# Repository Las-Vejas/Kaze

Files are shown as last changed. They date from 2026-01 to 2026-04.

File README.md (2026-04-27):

<h1 align="center">
  <br>
  <a href="https://vejas.zip">
    kaze_logo_kanji_center
  </a>
  <br>
  <sub>Kaze</sub>
  <br>
</h1>

<div align="center">
  
  
  
  
</div>

<h4 align="center">An all-in-one ambient sensor for <a href="https://www.home-assistant.io/">Home Assistant</a>, powered by the ESP32-C6.</h4>

<br>

## Overview

Kaze is a compact ambient sensor that measures a wide range of environmental data and exposes it to Home Assistant via ESPHome. It supports **Zigbee, Wi-Fi, Bluetooth, and Thread** out of the box thanks to the ESP32-C6 module.

## Sensors

| Sensor | Measurements |
|---|---|
| BME680 | Temperature, Humidity, Pressure, CO₂ / AQI |
| TSL25911FN | Illuminance (lux), IR |
| WS2812B | RGB status LED |

## Connectivity

The ESP32-C6-MINI-1 module provides:
- Wi-Fi
- Bluetooth 5
- Thread / Matter
- Zigbee

These will be utilised to connect to your Home Assistant setup and provide temperature readings.

## Software

Firmware is written for **ESPHome**, making it seamless to integrate with Home Assistant. *(Work in progress)*

## Images

<p align="center">
  
  
  
  
</p>
<p align="center">
  
</p>

## Bill of Materials

### JLCPCB

| Item | Cost |
|---|---|
| PCB (5×) | $2.10 |
| Stencil | $7.00 |
| Shipping (Global Standard Direct Line) | $26.55 |

### LCSC Components

| Part | Mfr. | Qty | Unit Price | Ext. Price | LCSC# |
|---|---|-----|---|---|---|
| ESP32-C6-MINI-1-N4 | Espressif | 2 | $4.04 | $8.09 | [C5736265](https://www.lcsc.com/product-detail/C5736265.html) |
| BME680 | Bosch | 1 | $9.85 | $9.85 | [C125972](https://www.lcsc.com/product-detail/C125972.html) |
| TSL25911FN | AMS | 3 | $1.81 | $5.42 | [C176812](https://www.lcsc.com/product-detail/C176812.html) |
| MCP73831T-2ACI/OT | Microchip | 2 | $0.73 | $1.46 | [C424093](https://www.lcsc.com/product-detail/C424093.html) |
| AP2112K-3.3TRG1 (LDO 3.3V) | Tech Public | 5 | $0.09 | $0.47 | [C23380830](https://www.lcsc.com/product-detail/C23380830.html) |
| WS2812B-2020 (RGB LED) | Worldsemi | 10 | $0.08 | $0.83 | [C965555](https://www.lcsc.com/product-detail/C965555.html) |
| USB-C Receptacle 16P | Shou Han | 20 | $0.06 | $1.20 | [C2765186](https://www.lcsc.com/product-detail/C2765186.html) |
| Tactile Switch SPST | Alps Alpine | 5 | $0.13 | $0.65 | [C115357](https://www.lcsc.com/product-detail/C115357.html) |
| Cap 100nF 0402 | Samsung EM | 100 | $0.005 | $0.49 | [C16193311](https://www.lcsc.com/product-detail/C16193311.html) |
| Cap 4.7µF 0402 | Samsung EM | 20 | $0.009 | $0.18 | [C318563](https://www.lcsc.com/product-detail/C318563.html) |
| Cap 10µF 0402 | Samsung EM | 50 | $0.012 | $0.59 | [C3902158](https://www.lcsc.com/product-detail/C3902158.html) |
| Cap 1µF 16V 0402 | Samsung EM | 100 | $0.002 | $0.23 | [C29266](https://www.lcsc.com/product-detail/C29266.html) |
| Cap 1µF 10V 0402 | Samsung EM | 100 | $0.002 | $0.18 | [C14445](https://www.lcsc.com/product-detail/C14445.html) |
| Res 10kΩ 0402 | Yageo | 100 | $0.001 | $0.07 | [C60489](https://www.lcsc.com/product-detail/C60489.html) |
| Res 4.7kΩ 0402 | Yageo | 100 | $0.001 | $0.07 | [C105870](https://www.lcsc.com/product-detail/C105870.html) |
| Res 2.4kΩ 0402 | Yageo | 100 | $0.001 | $0.07 | [C137889](https://www.lcsc.com/product-detail/C137889.html) |
| Res 5.1kΩ 0402 | Yageo | 100 | $0.001 | $0.08 | [C105872](https://www.lcsc.com/product-detail/C105872.html) |
| Res 22Ω 0402 | Yageo | 100 | $0.001 | $0.07 | [C114765](https://www.lcsc.com/product-detail/C114765.html) |

### Other

| Item | Cost |
|---|---|
| LiPo Battery 3.7V 800mAh (802540) | $6.52 |
| LCSC Shipping | $9.50 |

### 💰 Total Cost Estimate

| | |
|---|---|
| LCSC components + shipping | ~$38.00 |
| JLCPCB PCB + stencil + shipping | ~$35.65 |
| Battery | $6.52 |
| Discounts | −$5.10 |
| **Total** | **~$76.67** |

> Shipping cost for JLCPCB can be roughly halved if ordered alongside another project.

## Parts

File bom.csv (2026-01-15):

Kaze BOM
JLCPCB BOM
Index | Item | Price | Note
1 | PCB from JLCPCB | 2.10 $US
2 | Stencil | 7.00 $US
3 | JLCPCB Shipping | 26.55 $US | Cheapest possible. (Global Standard Direct Line), possible to reduce in half if ordered with other project
Digikey BOM
Index | Manufacturer Part Number | Total Price | Description | Quantity | Pack Type | Digi-Key Part Number | Unit Price | Manufacturer Name | Reference Designator
1 | ESP32-C6-MINI-1-N4 | 9.02 $US | RF TXRX MOD BT WIFI PCB TH SMD | 2 | Cut Tape (CT) | 1965-ESP32-C6-MINI-1-H4CT-ND | 4.51 | Espressif Systems | U4
2 | SKRKAEE020 | 1.64 $US | SWITCH TACTILE SPST-NO 0.05A 12V | 4 | Cut Tape (CT) | 4809-SKRKAEE020CT-ND | 0.41000 | Alps Alpine | SW1, SW2
3 | BME680 | 17.30 $US | SENSOR GAS/HUM/PRES/TEMP I2C SPI | 2 | Cut Tape (CT) | 828-1077-1-ND | 8.65000 | Bosch Sensortec | U2
4 | TSL25911FN | 3.34 $US | SENSOR OPT AMBIENT 6 WFDFN | 2 | Cut Tape (CT) | TSL25911FNCT-ND | 1.67000 | ams-OSRAM USA INC. | U1
5 | 4684 | 3.95 $US | ADDRESS LED DISCRETE RGB | 1 | Bag | 1528-4684-ND | 3.95000 | Adafruit Industries LLC | D1, D2, D3, D4, D5
6 | USB4105-GF-A | 1.56 $US | CONN RCP USB2.0 TYP C 16P SMD RA | 2 | Cut Tape (CT) | 2073-USB4105-GF-ACT-ND | 0.78000 | GCT | P1
7 | AP2112K-3.3TRG1 | 0.44 $US | IC REG LINEAR 3.3V 600MA SOT-25 | 2 | Cut Tape (CT) | AP2112K-3.3TRG1DICT-ND | 0.22000 | Diodes Incorporated | U3
8 | MCP73831T-2ACI/OT | 1.52 $US | IC BATT CNTL LI-ION 1CEL SOT23-5 | 2 | Cut Tape (CT) | MCP73831T-2ACI/OTCT-ND | 0.76000 | Microchip Technology | U5
9 | CL05B104KP5VPNC | 0.74 $US | CAP CER 100NF 10V X7R 0402 | 20 | Cut Tape (CT) | 1276-CL05B104KP5VPNCCT-ND | 0.03700 | Samsung Electro-Mechanics | C1, C8, C10, C12, C13, C14, C15, C16, C2, C5
10 | CL05A475MO5NUNC | 0.32 $US | CAP CER 4.7UF 16V X5R 0402 | 4 | Cut Tape (CT) | 1276-6836-1-ND | 0.08000 | Samsung Electro-Mechanics | C11, C17
11 | CL05A106MP6NUN8 | 0.48 $US | CAP CER 10UF 10V X5R 0402 | 4 | Cut Tape (CT) | 1276-CL05A106MP6NUN8CT-ND | 0.12000 | Samsung Electro-Mechanics
12 | RC0402JR-0710KL | 0.12 $US | RES 10K OHM 5% 1/16W 0402 | 20 | Cut Tape (CT) | 311-10KJRCT-ND | 0.00600 | YAGEO
13 | RC0402JR-074K7L | 0.03 $US | RES 4.7K OHM 5% 1/16W 0402 | 10 | Cut Tape (CT) | 311-4.7KJRCT-ND | 0.00300 | YAGEO
14 | RC0402FR-0722RL | 0.07 $US | RES 22 OHM 1% 1/16W 0402 | 10 | Cut Tape (CT) | 311-22.0LRCT-ND | 0.00700 | YAGEO
15 | RC0402JR-072K4L | 0.20 $US | RES 2.4K OHM 5% 1/16W 0402 | 2 | Cut Tape (CT) | 311-2.4KJRCT-ND | 0.10000 | YAGEO
16 | RC0402FR-075K1L | 0.08 $US | RES 5.1K OHM 1% 1/16W 0402 | 10 | Cut Tape (CT) | 311-5.10KLRCT-ND | 0.00800 | YAGEO
17 | CL05A105KO5NNNC | 0.06 $US | CAP CER 1UF 16V X5R 0402 | 10 | Cut Tape (CT) | 1276-1067-1-ND | 0.00600 | Samsung Electro-Mechanics
18 | CL05A226MQ5N6J8 | 0.26 $US | CAP CER 22UF 6.3V X5R 0402 | 2 | Cut Tape (CT) | 1276-7090-1-ND | 0.13000 | Samsung Electro-Mechanics
TOTAL |  | 41.13 $US
TOTAL IN BOM |  | 76.78 $US

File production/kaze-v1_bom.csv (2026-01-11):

Designator | Footprint | Quantity | Value | LCSC Part #
C1, C4 | 0402 | 2 | 4.7u
C10, C11, C12, C14, C16, C2, C3, C8, C9 | 0402 | 9 | 100nf
C13, C15, C17, C18 | 0402 | 4 | 1uF
C19 | 0402 | 1 | 22uf
C5 | 0402 | 1 | 10uf
C6 | 0402 | 1 | 10u
C7 | 0402 | 1 | 100n
D1, D2, D3, D4, D5 | LED_WS2812B-2020_PLCC4_2.0x2.0mm | 5 | WS2812B-2020
IO2, IO3 | TestPoint_Pad_D3.0mm | 2 | TestPoint
J1 | PinHeader_2x01_P1.00mm_Vertical | 1 | Conn_01x02_Pin
P1 | USB_C_Receptacle_GCT_USB4105-xx-A_16P_TopMnt_Horizontal | 1 | USB_C_Plug_USB2.0
R1, R2 | 0402 | 2 | 5.1k
R10, R12, R8, R9_2, R9 | 0402 | 5 | 10k
R11 | 0402 | 1 | 4.7
R3, R4 | 0402 | 2 | 4.7k
R5, R6 | 0402 | 2 | 22
R7 | 0402 | 1 | 2.4k
SW1, SW2 | SW_Push_SPST_NO_Alps_SKRK | 2 | SW_Push
U1 | SOT-23-5 | 1 | MCP73831-2-OT
U2 | Bosch_LGA-8_3x3mm_P0.8mm_ClockwisePinNumbering | 1 | BME680
U3 | SOT-23-5 | 1 | AP2112K-3.3
U4 | ESP32-C6-MINI-1 | 1 | ESP32-C6-MINI-1
U5 | AMS_TSL25911FN | 1 | TSL25911FN
U6 | XCDR_SGP40-D-R4 | 1 | SGP40-D-R4

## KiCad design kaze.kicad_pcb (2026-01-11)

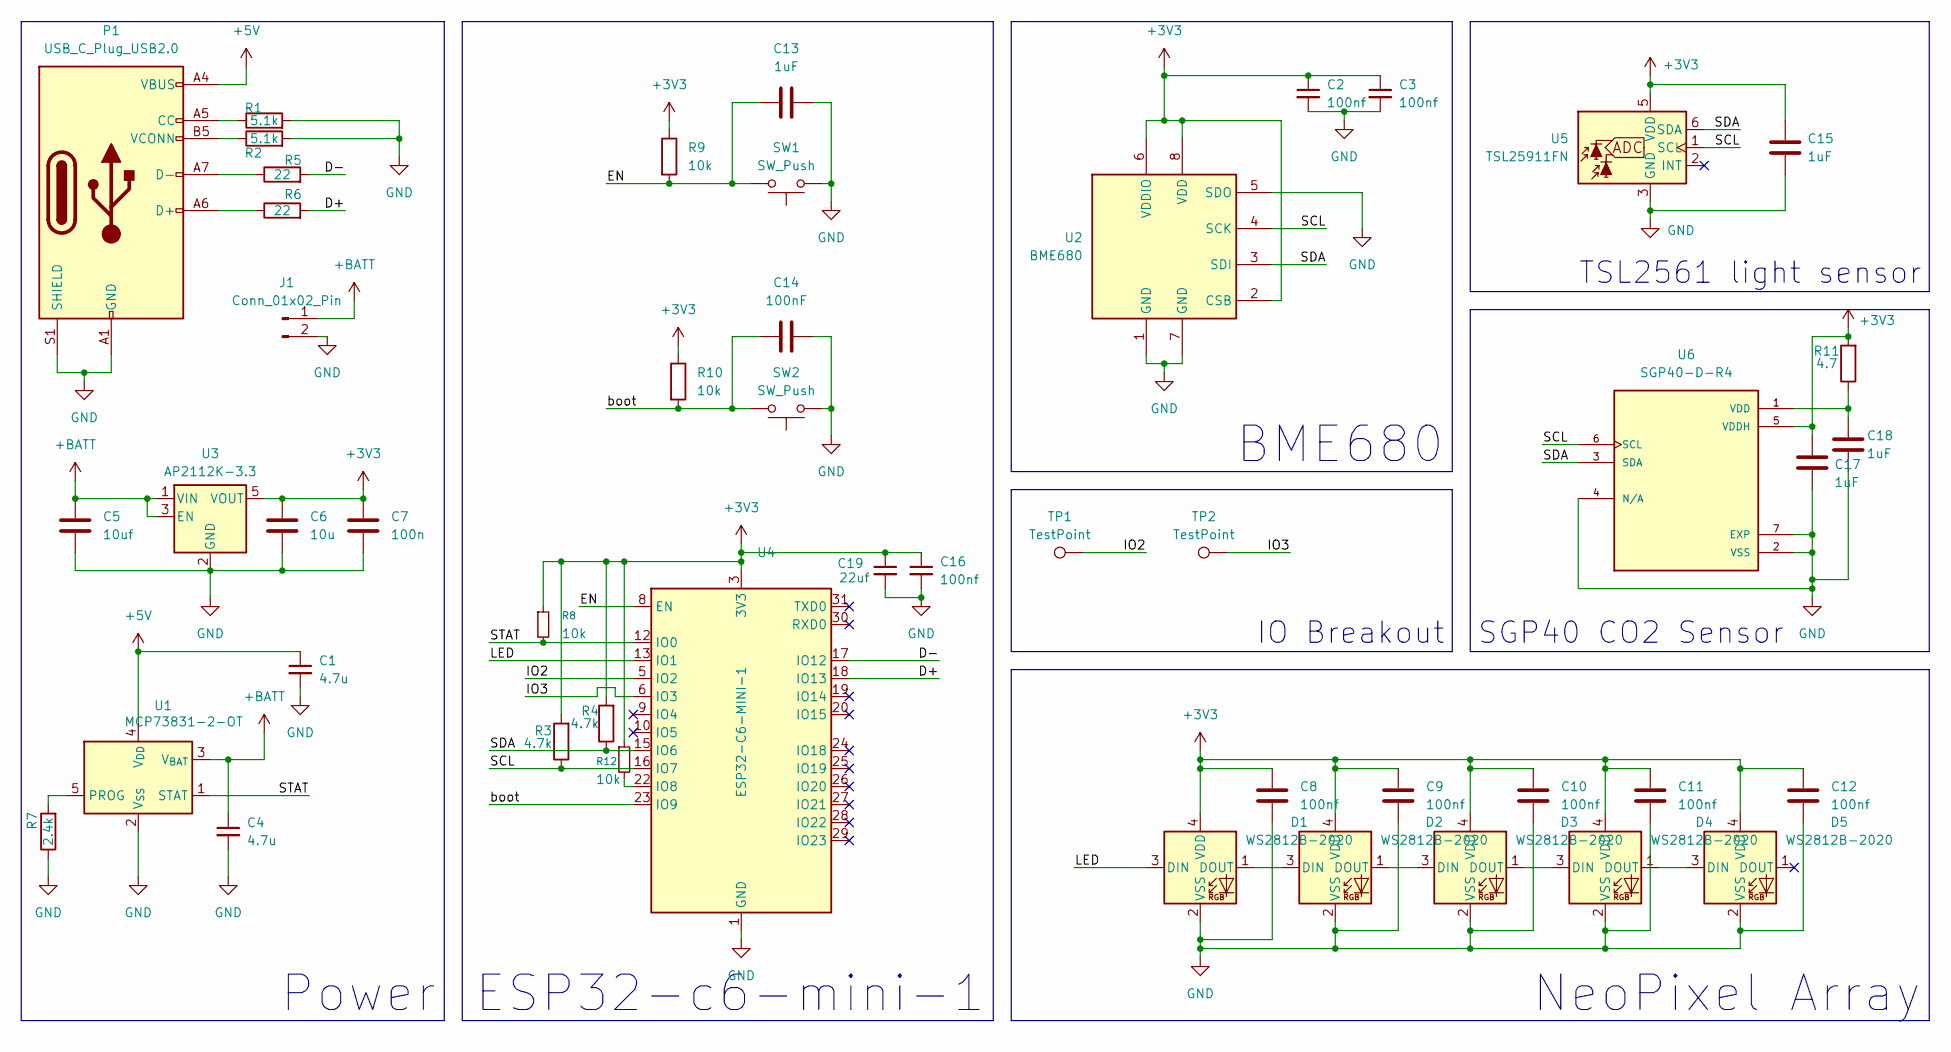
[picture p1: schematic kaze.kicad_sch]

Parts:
C1, C4: 4.7u; C_0402_1005Metric
C2, C3, C8, C9, C10, C11, C12, C16: 100nf; C_0402_1005Metric
C5: 10uf; C_0402_1005Metric
C6: 10u; C_0402_1005Metric
C7: 100n; C_0402_1005Metric
C13, C15, C17, C18: 1uF; C_0402_1005Metric
C14: 100nF; C_0402_1005Metric
C19: 22uf; C_0402_1005Metric
D1, D2, D3, D4, D5: WS2812B-2020; LED_WS2812B-2020_PLCC4_2.0x2.0mm
J1: Conn_01x02_Pin; PinHeader_2x01_P1.00mm_Vertical
P1: USB_C_Plug_USB2.0; USB_C_Receptacle_GCT_USB4105-xx-A_16P_TopMnt_Horizontal
R1, R2: 5.1k; R_0402_1005Metric
R3, R4: 4.7k; R_0402_1005Metric
R5, R6: 22; R_0402_1005Metric
R7: 2.4k; R_0402_1005Metric
R8, R9, R10, R12: 10k; R_0402_1005Metric
R11: 4.7; R_0402_1005Metric
SW1, SW2: SW_Push; SW_Push_SPST_NO_Alps_SKRK
TP1, TP2: TestPoint; TestPoint_Pad_D3.0mm
U1: MCP73831-2-OT; SOT-23-5
U2: BME680; Bosch_LGA-8_3x3mm_P0.8mm_ClockwisePinNumbering
U3: AP2112K-3.3; SOT-23-5
U4: ESP32-C6-MINI-1
U5: TSL25911FN; AMS_TSL25911FN
U6: SGP40-D-R4; XCDR_SGP40-D-R4; PARTREV 1.2

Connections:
+3V3: C2.1, C3.1, C6.1, C7.1, C8.1, C9.1, C10.1, C11.1, C12.1, C15.1, C16.1, C17.1, C19.1, D1.4 (VDD), D2.4 (VDD), D3.4 (VDD), D4.4 (VDD), D5.4 (VDD), R3.2, R4.2, R8.1, R9.1, R10.1, R11.2, R12.1, U2.2 (CSB), U2.6 (VDDIO), U2.8 (VDD), U3.5 (VOUT), U4.3 (3V3), U5.5 (VDD), U6.5 (VDDH); also elsewhere on the board
+5V: C1.1, P1.A4 (VBUS), P1.A9 (VBUS), P1.B4 (VBUS), P1.B9 (VBUS), U1.4 (V_{DD})
+BATT: C4.1, C5.1, J1.1, U1.3 (V_{BAT}), U3.1 (VIN), U3.3 (EN)
/D+: R6.2, U4.18 (IO13)
/D-: R5.2, U4.17 (IO12)
/EN: C13.1, R9.2, SW1.2, U4.8 (EN); also elsewhere on the board
/IO2: TP1.1, U4.5 (IO2); also elsewhere on the board
/IO3: TP2.1, U4.6 (IO3); also elsewhere on the board
/LED: D1.3 (DIN), U4.13 (IO1)
/SCL: R3.1, U2.4 (SCK), U4.16 (IO7), U5.1 (SCL), U6.6 (SCL)
/SDA: R4.1, U2.3 (SDI), U4.15 (IO6), U5.6 (SDA), U6.3 (SDA)
/STAT: R8.2, U1.1 (STAT), U4.12 (IO0)
/boot: C14.1, R10.2, SW2.2, U4.23 (IO9)
GND: C1.2, C2.2, C3.2, C4.2, C5.2, C6.2, C7.2, C8.2, C9.2, C10.2, C11.2, C12.2, C13.2, C14.2, C15.2, C16.2, C17.2, C18.2, C19.2, D1.2 (VSS), D2.2 (VSS), D3.2 (VSS), D4.2 (VSS), D5.2 (VSS), J1.2, P1.A1 (GND), P1.A12 (GND), P1.B1 (GND), P1.B12 (GND), P1.S1 (SHIELD), R1.2, R2.2, R7.1, SW1.1, SW2.1, U1.2 (V_{SS}), U2.1 (GND), U2.5 (SDO), U2.7 (GND), U3.2 (GND), U4.1 (GND), U4.2 (GND), U4.11 (GND), U4.14 (GND), U4.36 (GND), U4.37 (GND), U4.38 (GND), U4.39 (GND), U4.40 (GND), U4.41 (GND), U4.42 (GND), U4.43 (GND), U4.44 (GND), U4.45 (GND), U4.46 (GND), U4.47 (GND), U4.48 (GND), U4.49 (GND), U4.50 (GND), U4.51 (GND), U4.52 (GND), U4.53 (GND), U5.3 (GND), U6.2 (VSS), U6.4 (N/A), U6.7 (EXP)
unnamed: D1.1 (DOUT), D2.3 (DIN)
unnamed: D2.1 (DOUT), D3.3 (DIN)
unnamed: D3.1 (DOUT), D4.3 (DIN)
unnamed: D4.1 (DOUT), D5.3 (DIN)
unnamed: P1.A5 (CC), R1.1
unnamed: P1.A6 (D+), R6.1
unnamed: P1.A7 (D-), R5.1
unnamed: P1.B5 (VCONN), R2.1
unnamed: R7.2, U1.5 (PROG)
unnamed: R12.2, U4.22 (IO8)
unnamed: C18.1, R11.1, U6.1 (VDD)

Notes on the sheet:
TSL2561 light sensor
ESP32-c6-mini-1
NeoPixel Array
IO Breakout
SGP40 CO2 Sensor
Power
BME680

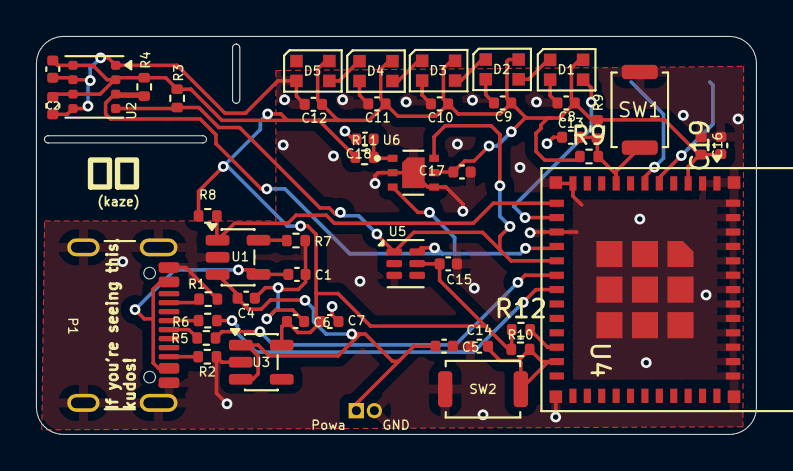
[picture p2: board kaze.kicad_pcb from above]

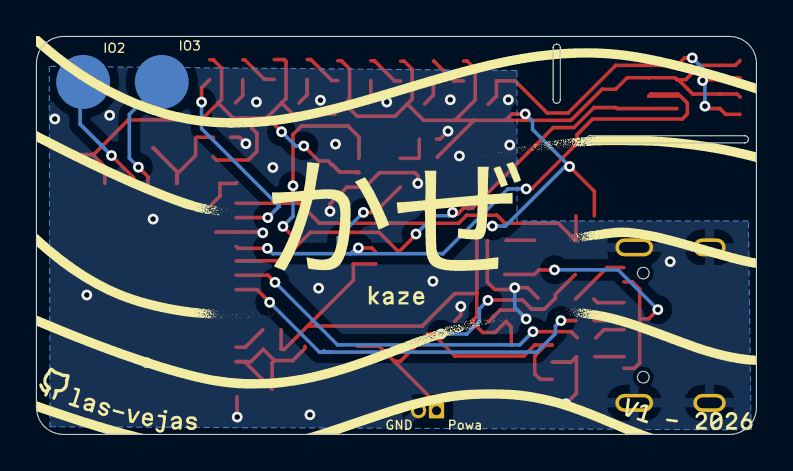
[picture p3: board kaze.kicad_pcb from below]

Board: 2 copper layers, 40.0 x 22.1 mm, 49 parts (2 on the bottom side), 25 nets.

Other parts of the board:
IO2, IO3: TestPoint; TestPoint_Pad_D3.0mm
R9#2: 10k; R_0402_1005Metric

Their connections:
+3V3: R9#2.1; also elsewhere on the board
/EN: R9#2.2; also elsewhere on the board
/IO2: IO2.1; also elsewhere on the board
/IO3: IO3.1; also elsewhere on the board

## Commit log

2026-01-28 Update README with BOM details and component links
    Added BOM tables for JLCPCB and LCSC components with pricing and links.
2026-04-25 Revise README with project overview and BOM
    Updated the README to include an overview, detailed sensor information, connectivity options, and a bill of materials with cost estimates.
